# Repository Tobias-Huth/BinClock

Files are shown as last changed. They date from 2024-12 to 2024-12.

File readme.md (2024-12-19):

english version below!

# Mega Projekt: Binäre Anzeige der Uhzeit mit LEDS
Die Idee war schon länger vorhanden und nachdem es dieses spezielle Ding nicht zu kaufen gibt: Hab ich da was gemacht

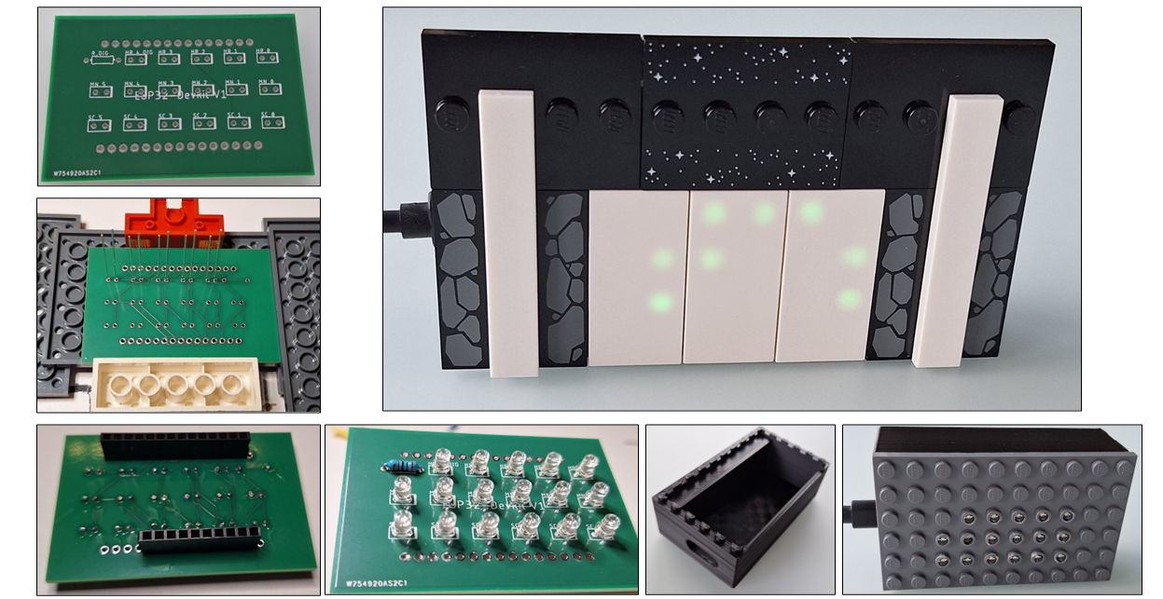
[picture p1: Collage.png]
image caption


## Allgemein:
Das ganze Projekt hat einen ESP32 (z.B [dieser](https://www.amazon.de/dp/B0DGG865GM)) als Kern. Der ESP hat 16 PWM-fähige Ausgänge. Das reicht fast, um die Uhrzeit anzuzeigen:
Minuten und Sekunden benötigen jeweils 6 Bit (0..63)
Die Stundenanzeige braucht 5 Bit (0..31). 
Das heißt, eine LED muss mit einem Widerstand fest beschalten werden, alle anderen können dimmbar sein. gar nicht so schlecht, machen wir so.
Nachdem diese Grundidee vorhanden ist, nun zur Umsetzung.

## Elektronik

Der zugegeben wirklich einfache Schaltplan für das Gerät ist in [Autodesk EAGLE](http://eagle.autodesk.com/eagle/software-versions/50) geschrieben. Die Software ist, soweit ich sehen kann, frei, nur eine Anmeldung ist nötig.
Um selbst was zu machen, empfehle ich dringend ein Tutorial wie dieses:
https://www.youtube.com/watch?v=1AXwjZoyNno
Damit versteht man die Bedienlogik und die Logik des Tools ganz gut.

Den Plan habe ich dann genutzt, um gerber-files (CNC-Dateien für die Platinen) herzustellen und bei [PCBway](https://www.pcbway.com/) zu bestellen. Die Anleitung [hier](https://www.pcbway.com/helpcenter/generate_gerber/Generate_Gerber_files_in_Eagle.html) hat bei mir sehr gut funktioniert.

## CAD / Gehäuse
Wie man unschwer erkennen kann, ist die Frontplatte eine Lego Bauplatte, 10x6 Noppen. Die Noppen ( ⌀ 4.9 mm) sind mit einem Bohrer 3,3mm ausgebohrt. So passen die 3mm-LEDs locker. Der erste Prototyp mit 3mm goßem Loch hat zwar schön geklemmt, die LEDs vertragen aber die Kräfte beim Aufsetzen nicht gut.
Die Platine benutzt das Lego-Rastermaß 8 mm. So passen die LEDs auf der Paltine sauber in die Löcher.
Das Gehäuse selbst ist in [FreeCAD](https://www.freecad.org/) konstruiert und dann gedruckt.

## Software
Die Software ist in [Arduino-IDE](https://www.arduino.cc/en/software) geschrieben. Die notwendigen Bibliotheken versuche ich weiter unten zusammenzutragen.
Der ESP stellt einen WLAN-Access-Point zu Verfügung. In diesem Netz serviert der ESP die Webseite, mit der die Uhr gestellt wird. Die Steuerung wird über http-request (POST) realisiert.
Die in [Brave](https://brave.com/) enthaltene KI hat mir wirklich gut geholfen, den Teil der Verarbeitung der http-requests im Backend einfach zu implementieren.
Ich hab die ASCII-Tabelle abprogrammiert, die Uhr kann mit ihrem 3x5 großen Anzeigefeld alle Buchstaben, Ziffern und ein paar Sonderzeichen darstellen.

---

## Stückliste
- 17 3-mm-LEDS wie diese :https://www.amazon.de/gp/product/B01BTYHOMC/
- PCB nach EAGLE-Plan
- ESP32 https://www.amazon.de/gp/product/B0DGG865GM/
- 2kOhm widerstand als Bremswiderstand für die LED am gigitalen Ausgang

---
---
# Mega Project: Binary Display of Time with LEDs
The idea had been around for a while, and since this special thing couldn’t be bought, I decided to make one myself.

image caption

## General:
The entire project is based on an ESP32 (e.g. [this one](https://www.amazon.de/dp/B0DGG865GM)), which has 16 PWM-capable outputs. This is almost enough to display the time:

Minutes and seconds each require 6 bits (0…63)
The hour display needs 5 bits (0…31). This means that one LED must be connected with a fixed resistor, and all others can be dimmable. Not so bad, let’s do it that way. Now that the basic idea is in place, let’s move on to the implementation.

## Electronics
The admittedly very simple circuit diagram for the device is written in [Autodesk EAGLE](http://eagle.autodesk.com/eagle/software-versions/50). The software is, as far as I can see, free, but requires registration. To get started, I strongly recommend a tutorial like this: https://www.youtube.com/watch?v=1AXwjZoyNno 
This will help you understand the logic and tool usage quite well.

I used the plan to create gerber files (CNC files for the boards) and ordered them from [PCBway](https://www.pcbway.com/). The instructions [hier](https://www.pcbway.com/helpcenter/generate_gerber/Generate_Gerber_files_in_Eagle.html) worked very well for me.

## CAD / Housing
As you can easily recognize, the front panel is a Lego building plate, 10x6 studs. The studs (⌀ 4.9 mm) are drilled with a 3.3mm drill bit. This allows the 3mm LEDs to fit snugly. The first prototype with a 3mm large hole did fit nicely, but the LEDs don’t handle the forces of being placed well. The board uses the Lego grid size of 8 mm. This allows the LEDs on the board to fit cleanly into the holes. The housing itself is constructed in [FreeCAD](https://www.freecad.org/) and then printed at home.

## Software
The software is written in the [Arduino-IDE](https://www.arduino.cc/en/software). I’ll try to gather the necessary libraries below. The ESP provides a Wi-Fi access point. In this network, the ESP serves the webpage that sets the clock. The control is realized via HTTP requests (POST). Especially the http-request part on the backend was strongly supported by AI, namely the one included in [Brave](https://brave.com/).
I programmed the ASCII table, and the clock can display all letters, numbers, and a few special characters with its 3x5 large display field.

---
## Parts List
- 17 3mm LEDs like these: https://www.amazon.de/gp/product/B01BTYHOMC/
- PCB according to EAGLE plan
- ESP32: https://www.amazon.de/gp/product/B0DGG865GM/
- 2kOhm resistor as a braking resistor for the LED at the digital output

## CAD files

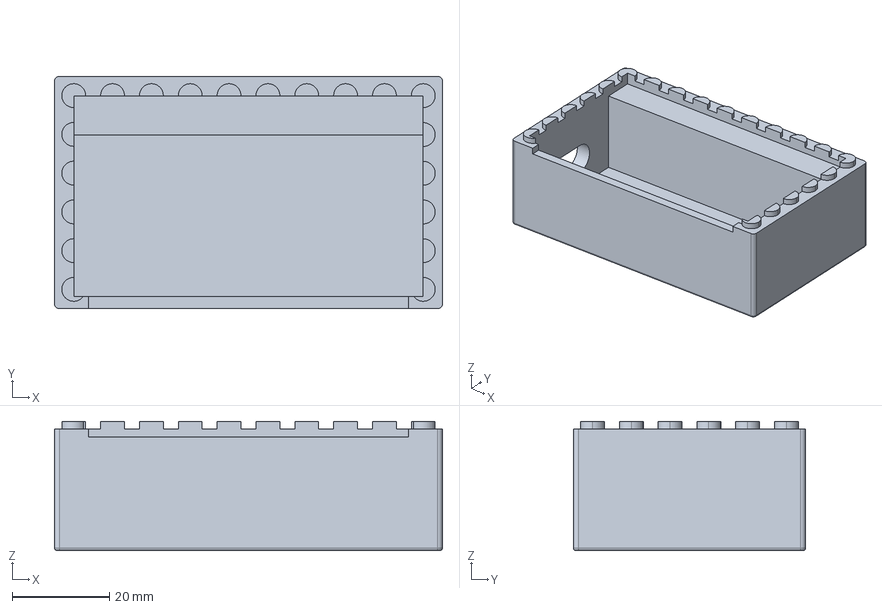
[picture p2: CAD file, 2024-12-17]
CAD/BinClock_House.FCStd
79.7 x 47.7 x 26.5 mm

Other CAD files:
CAD/BinClock_Assembly.FCStd
CAD/BinClock_House.stl

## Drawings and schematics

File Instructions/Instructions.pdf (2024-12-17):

## Temple Of Time

1

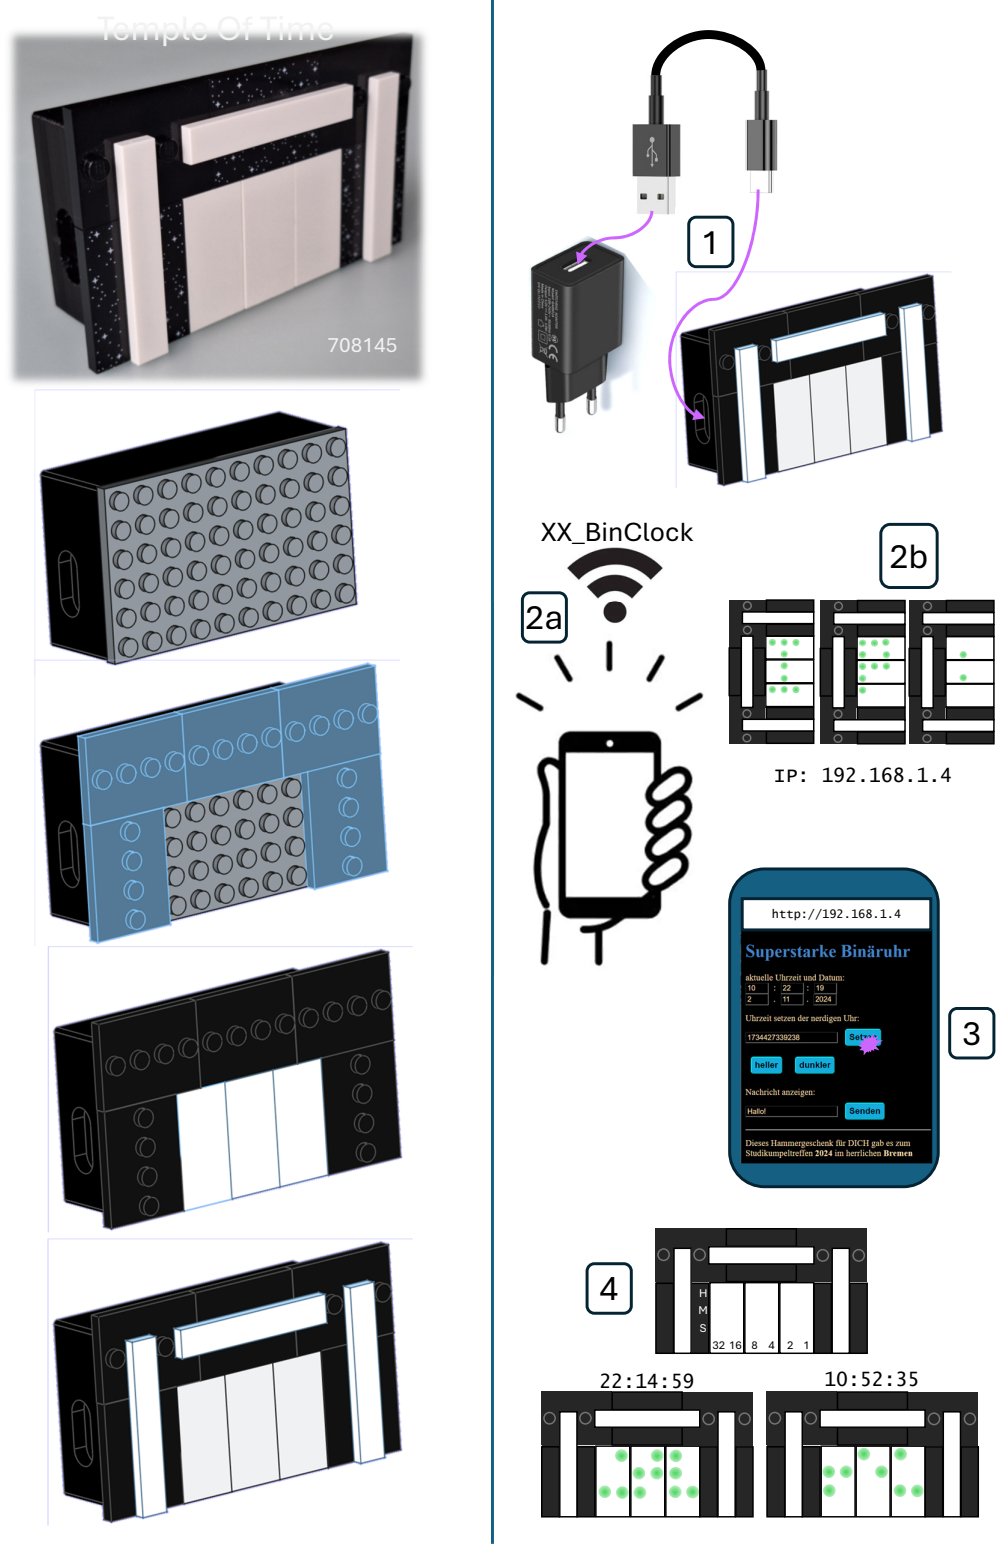
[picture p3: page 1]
XX_BinClock; http://192.168.1.4

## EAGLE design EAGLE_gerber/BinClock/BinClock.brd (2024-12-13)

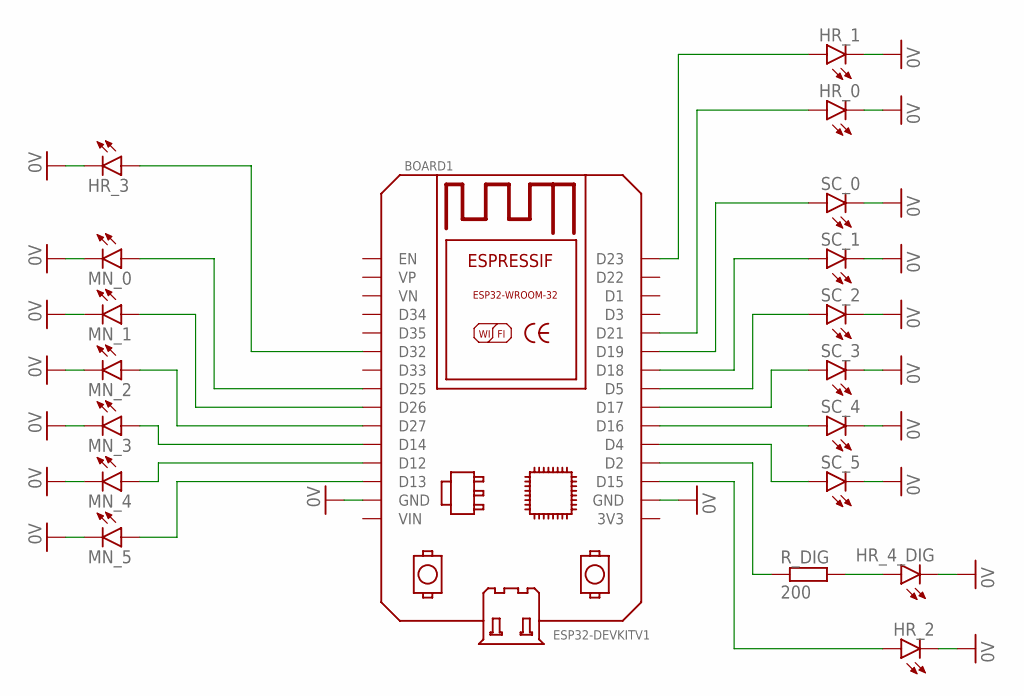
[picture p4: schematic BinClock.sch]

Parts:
BOARD1: ESP32DEVKITV1; ESP32-DEVKITV1
HR_0, HR_1, HR_2, HR_3, HR_4_DIG: LEDSQR2X5; LED2X5
MN_0, MN_1, MN_2, MN_3, MN_4, MN_5: LEDSQR2X5; LED2X5
R_DIG: 200; 0204/7
SC_0, SC_1, SC_2, SC_3, SC_4, SC_5: LEDSQR2X5; LED2X5

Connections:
0V: BOARD1.GND, BOARD1.GND@1 (GND), HR_0.K (C), HR_1.K (C), HR_2.K (C), HR_3.K (C), HR_4_DIG.K (C), MN_0.K (C), MN_1.K (C), MN_2.K (C), MN_3.K (C), MN_4.K (C), MN_5.K (C), SC_0.K (C), SC_1.K (C), SC_2.K (C), SC_3.K (C), SC_4.K (C), SC_5.K (C)
unnamed: BOARD1.D4, SC_5.A
unnamed: BOARD1.D16, SC_4.A
unnamed: BOARD1.D17, SC_3.A
unnamed: BOARD1.D5, SC_2.A
unnamed: BOARD1.D18, SC_1.A
unnamed: BOARD1.D19, SC_0.A
unnamed: BOARD1.D2, R_DIG.1
unnamed: BOARD1.D13, MN_5.A
unnamed: BOARD1.D12, MN_4.A
unnamed: BOARD1.D14, MN_3.A
unnamed: BOARD1.D27, MN_2.A
unnamed: BOARD1.D26, MN_1.A
unnamed: BOARD1.D25, MN_0.A
unnamed: HR_4_DIG.A, R_DIG.2
unnamed: BOARD1.D21, HR_0.A
unnamed: BOARD1.D23, HR_1.A
unnamed: BOARD1.D15, HR_2.A
unnamed: BOARD1.D32, HR_3.A

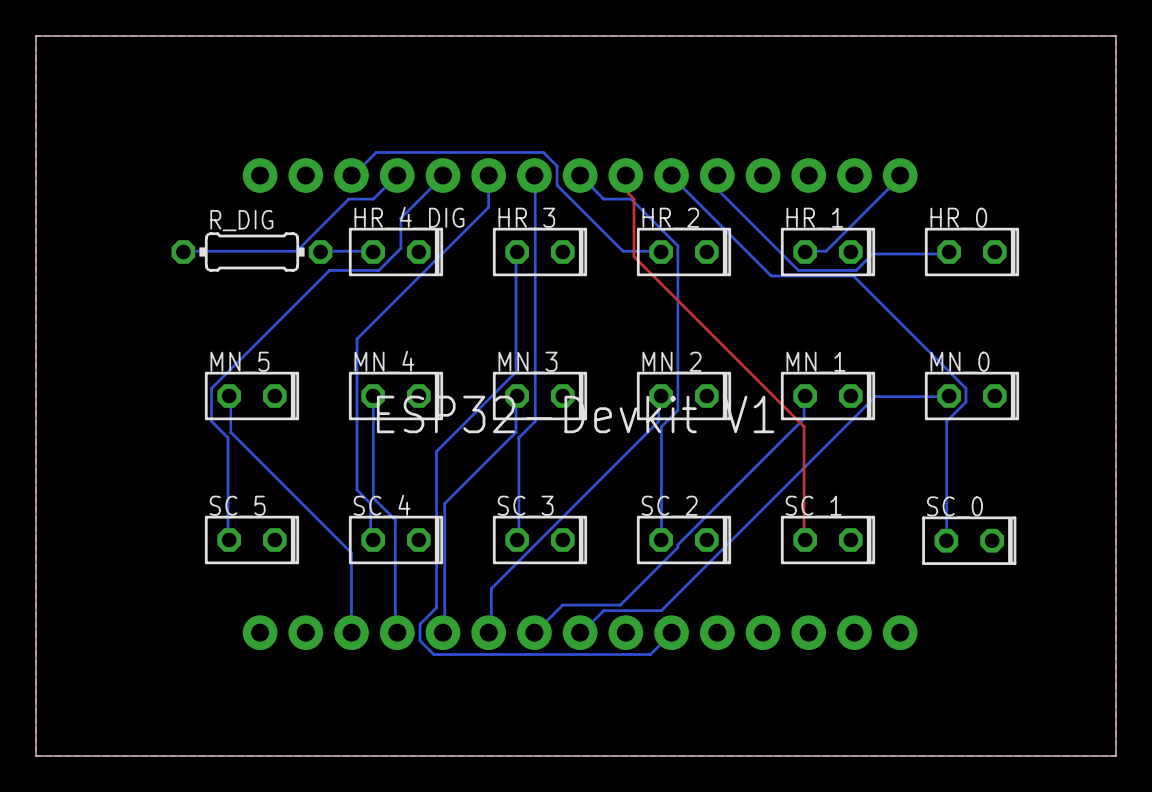
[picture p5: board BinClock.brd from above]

Board: 2 copper layers, 60.0 x 40.0 mm, 19 parts (1 on the bottom side), 19 nets.

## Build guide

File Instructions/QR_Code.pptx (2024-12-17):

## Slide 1

https://github.com/Tobias-Huth/BinClock

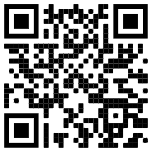
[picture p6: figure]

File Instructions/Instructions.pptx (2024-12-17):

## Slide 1

Temple Of Time

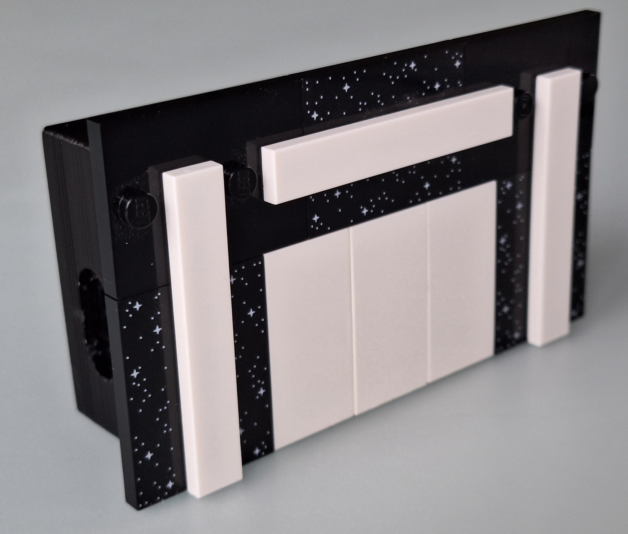
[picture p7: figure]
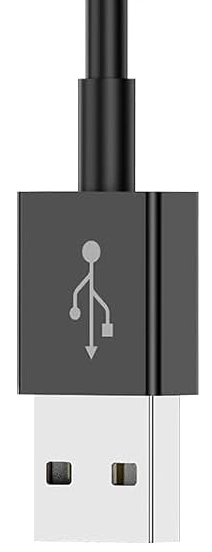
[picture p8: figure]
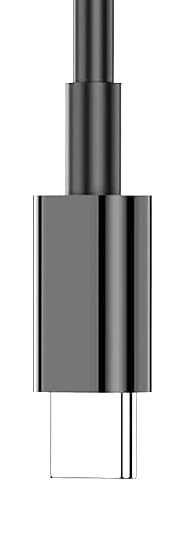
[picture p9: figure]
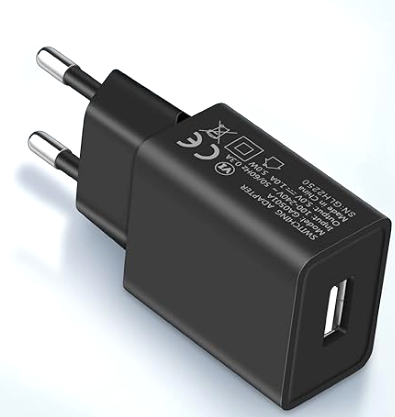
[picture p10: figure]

1

708145

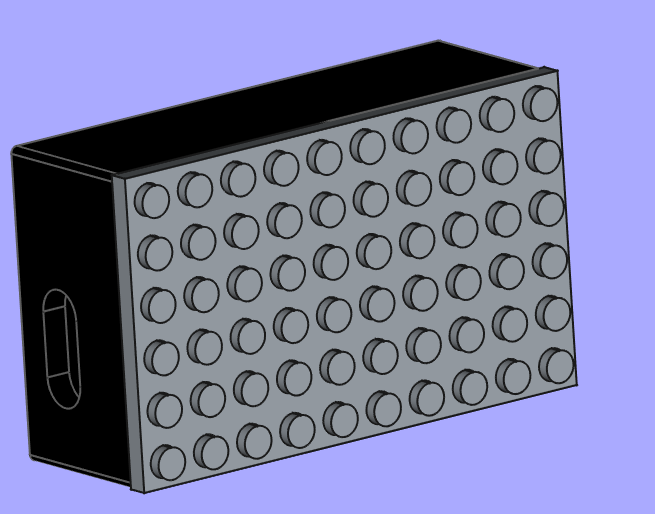
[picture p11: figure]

XX_BinClock

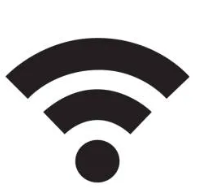
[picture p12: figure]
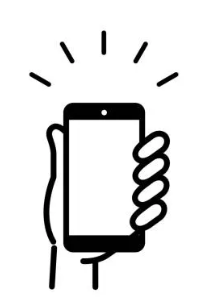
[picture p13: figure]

2a

2b

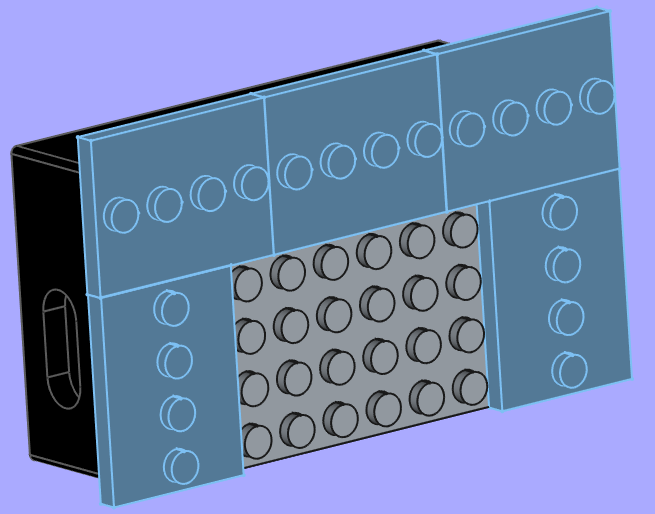
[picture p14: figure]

IP: 192.168.1.4

http://192.168.1.4

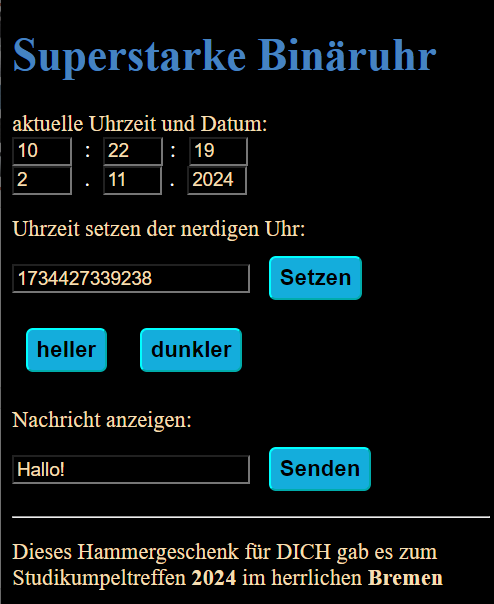
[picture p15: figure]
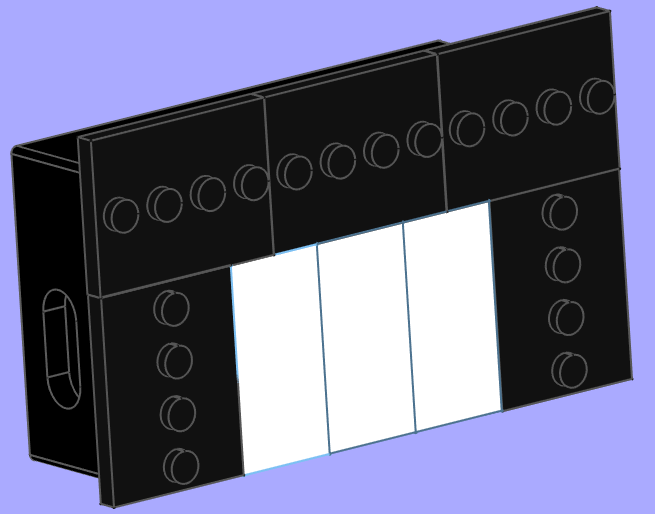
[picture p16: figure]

3

M

H

22:14:59

S

32

16

8

4

2

1

10:52:35

4

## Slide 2

1

1

XX_BinClock

XX_BinClock

2a

2b

2a

2b

IP: 192.168.1.4

http://192.168.1.4

IP: 192.168.1.4

http://192.168.1.4

3

3

M

H

22:14:59

S

32

16

8

4

2

1

10:52:35

4

M

H

22:14:59

S

32

16

8

4

2

1

10:52:35

4

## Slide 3

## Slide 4

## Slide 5

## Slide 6

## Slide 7

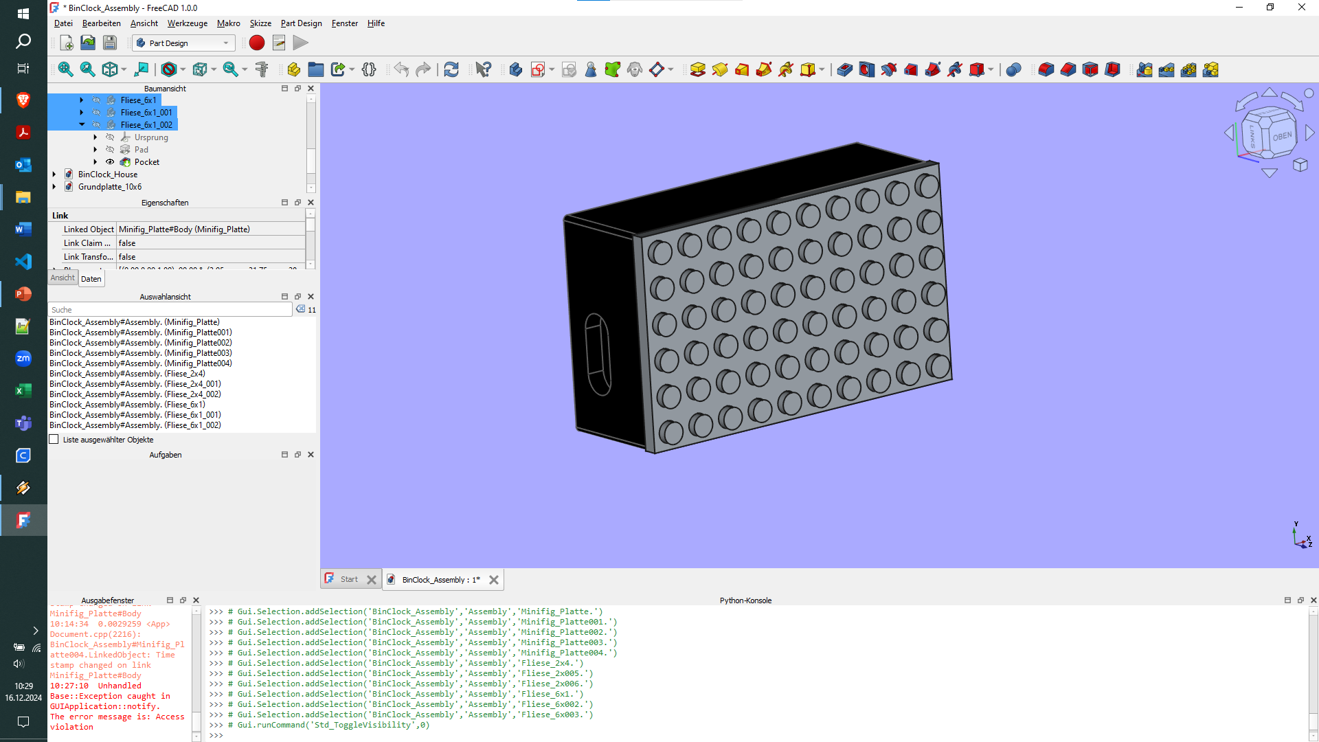
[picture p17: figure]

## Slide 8

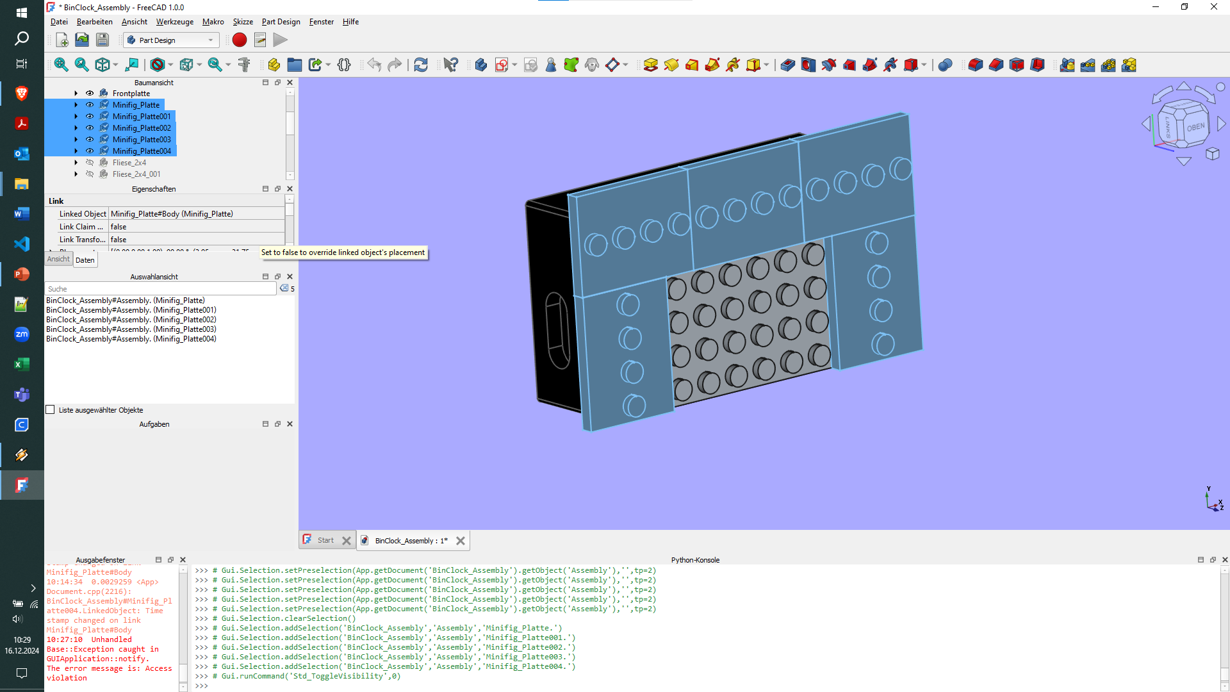
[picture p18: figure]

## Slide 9

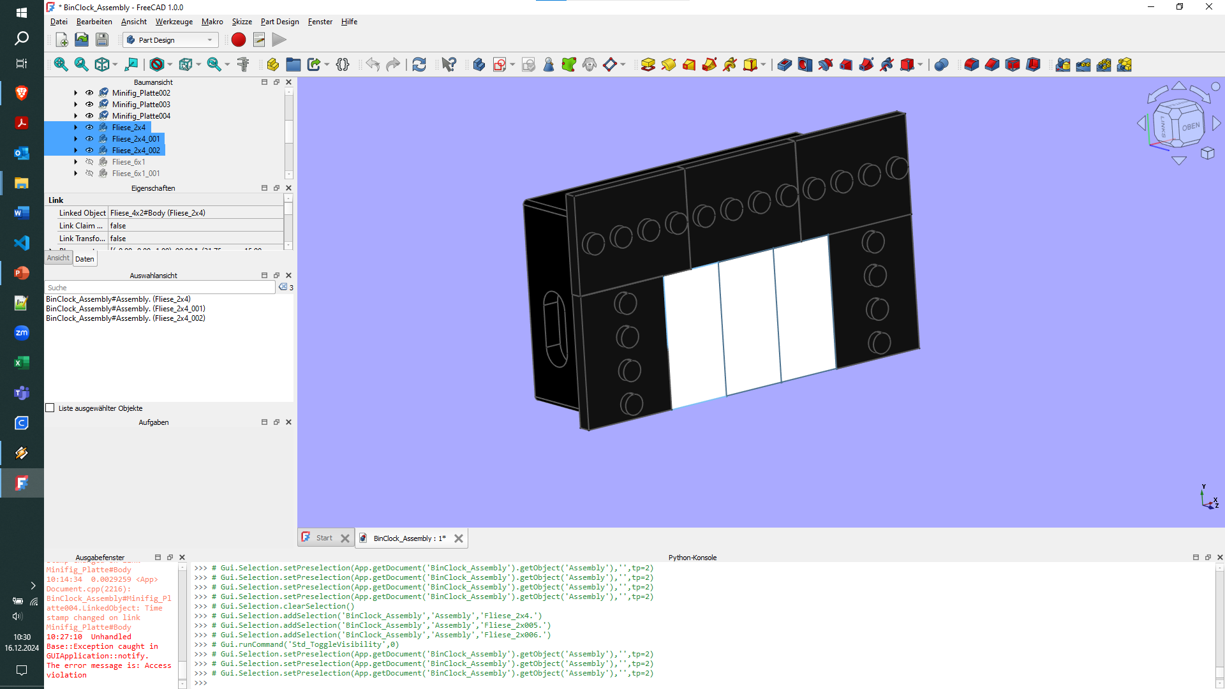
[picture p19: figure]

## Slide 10

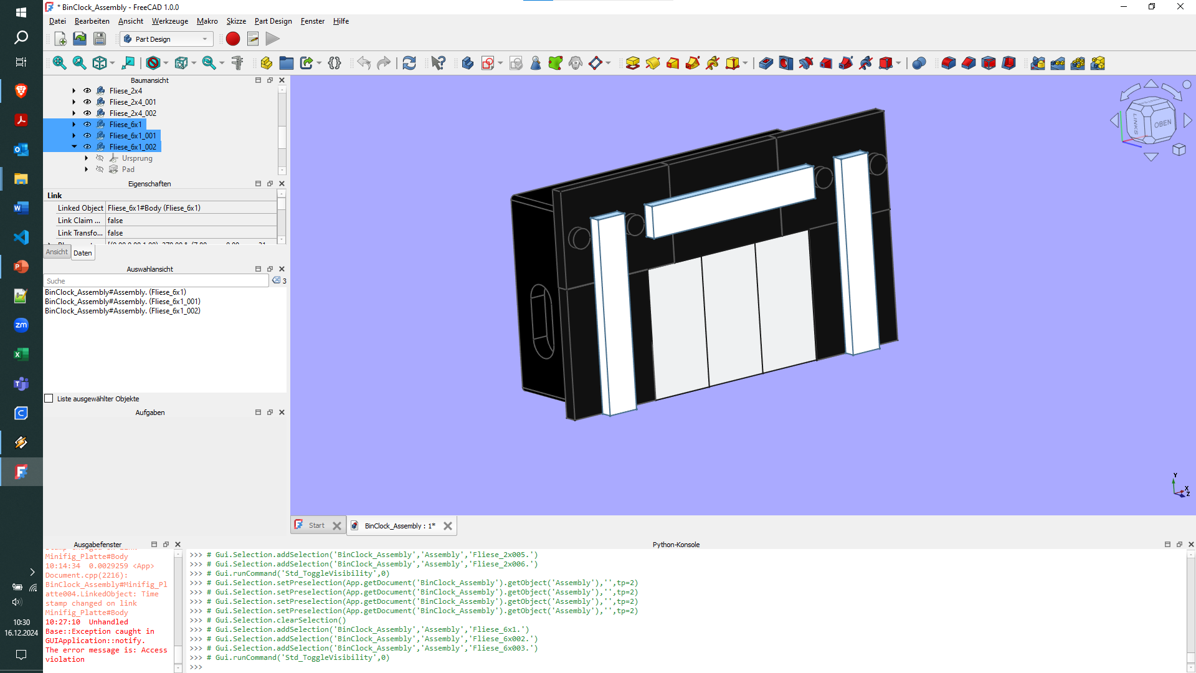
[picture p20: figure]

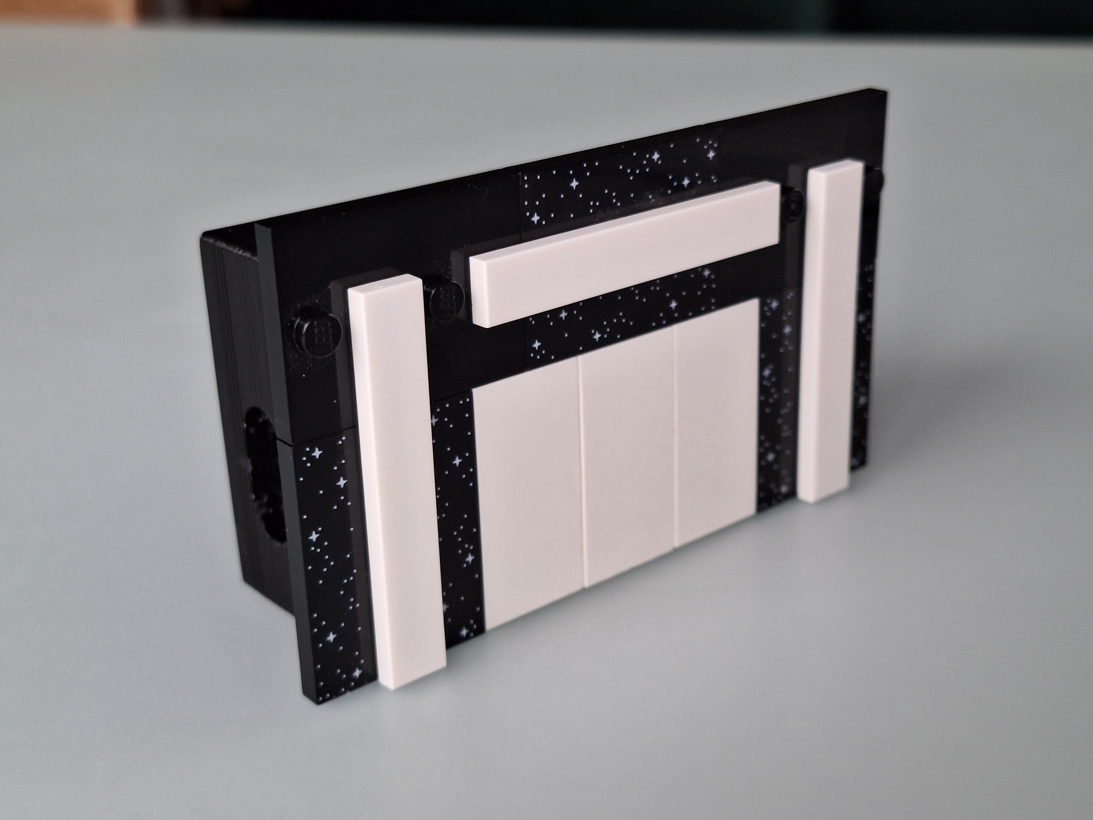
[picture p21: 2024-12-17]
Instructions/20241216_095956.jpg

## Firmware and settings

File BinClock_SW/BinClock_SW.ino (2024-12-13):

#include <WiFi.h>
#include <WebServer.h>
#include <ESP32Time.h>

#include "website.h"
#include "Pins_and_Counters.h"
#include "ASCII_Table.h"

const char* ssid = "BinClock";
const char* password = "";

int sec_cnt = -3;

int Sec_Val = 0;
int Min_Val = 0;
int Hur_Val = 0;

int bright_inc = 2;

int sec_bright = 10;
int min_bright = 10;
int hur_bright = 10;
int max_bright = 40;

bool IP_disp_done = false;

bool disp_user_Flag = false;
int disp_user_cnt = 0;
String message_string = "";
char* test_Arr = new char[128];


ESP32Time rtc(3600);  // set timezone to german gmt+1

IPAddress myIP;

WebServer server(80);

void setup() {
  pinMode(sec_Pin0, OUTPUT);
  pinMode(sec_Pin1, OUTPUT);
  pinMode(sec_Pin2, OUTPUT);
  pinMode(sec_Pin3, OUTPUT);
  pinMode(sec_Pin4, OUTPUT);
  pinMode(sec_Pin5, OUTPUT);

  pinMode(min_Pin0, OUTPUT);
  pinMode(min_Pin1, OUTPUT);
  pinMode(min_Pin2, OUTPUT);
  pinMode(min_Pin3, OUTPUT);
  pinMode(min_Pin4, OUTPUT);
  pinMode(min_Pin5, OUTPUT);

  pinMode(hur_Pin0, OUTPUT);
  pinMode(hur_Pin1, OUTPUT);
  pinMode(hur_Pin2, OUTPUT);
  pinMode(hur_Pin3, OUTPUT);
  pinMode(hur_Pin4, OUTPUT);

  Serial.begin(115200);
  WiFi.softAP(ssid, password);
  myIP = WiFi.softAPIP();

  server.on("/", handleRoot);
  server.begin();
}

void handleRoot() {

  if (server.method() == HTTP_POST) {
    String str_time_set = server.arg("set_T");
    String str_set_dimmer = server.arg("dimmer");
    String str_set_brighter = server.arg("brighter");
    String str_message = server.arg("message_Box");

    if (str_time_set.length() > 0) {
      Serial.println("Received post to set new time: " + str_time_set);
      char* pEnd;
      long long int time_val = strtoull(str_time_set.c_str(), &pEnd, 10) / 1000;
      rtc.setTime(time_val);
    }
    if (str_set_brighter.length() > 0) {
      Serial.println("set brightness higher");
      sec_bright += bright_inc;
      min_bright += bright_inc;
      hur_bright += bright_inc;
      if (sec_bright > max_bright) { sec_bright = max_bright; };
      if (min_bright > max_bright) { min_bright = max_bright; };
      if (hur_bright > max_bright) { hur_bright = max_bright; };
    }
    if (str_set_dimmer.length() > 0) {
      Serial.println("set the brightness lower");
      sec_bright -= bright_inc;
      min_bright -= bright_inc;
      hur_bright -= bright_inc;
      if (sec_bright < 1) { sec_bright = 1; };
      if (min_bright < 1) { min_bright = 1; };
      if (hur_bright < 1) { hur_bright = 1; };

      Serial.println(sec_bright);
    }
    if (str_message.length() > 0) {
      message_string = str_message;
      disp_user_Flag = true;
      disp_user_cnt = 0;
      strcpy(test_Arr, message_string.c_str());
    }

    server.send(200, "text/html", websiteHTML);

  } else {
    server.send(200, "text/html", websiteHTML);
  }
}

void loop() {

  server.handleClient();
  if (!IP_disp_done) {
    if (sec_cnt <= 0) {
      Sec_Val = 63;
      Min_Val = 63;
      Hur_Val = 31;
    }

    sec_cnt++;

    if (sec_cnt == 1) {
      Sec_Val = ASCII_table['I'-32][2];
      Min_Val = ASCII_table['I'-32][1];
      Hur_Val = ASCII_table['I'-32][0];
    }

    if (sec_cnt == 2) {
      Sec_Val = ASCII_table['P'-32][2];
      Min_Val = ASCII_table['P'-32][1];
      Hur_Val = ASCII_table['P'-32][0];
    }

    if (sec_cnt == 3) {
      Sec_Val = ASCII_table[':'-32][2];
      Min_Val = ASCII_table[':'-32][1];
      Hur_Val = ASCII_table[':'-32][0];
    }

    if ((sec_cnt > 3) & (sec_cnt < 16)) {
      char* temp_Arr = new char[35];
      strcpy(temp_Arr, myIP.toString(0).c_str());
        Sec_Val = ASCII_table[(temp_Arr[sec_cnt - 4]) - 32][2];
        Min_Val = ASCII_table[(temp_Arr[sec_cnt - 4]) - 32][1];
        Hur_Val = ASCII_table[(temp_Arr[sec_cnt - 4]) - 32][0];
    }
    if (sec_cnt == 16) {
      Sec_Val = 63;
      Min_Val = 63;
      Hur_Val = 31;
      IP_disp_done = true;
      sec_cnt = 0;
    }
  } else if (disp_user_Flag) {
    Sec_Val = ASCII_table[(int)test_Arr[disp_user_cnt] - 32][2];
    Min_Val = ASCII_table[(int)test_Arr[disp_user_cnt] - 32][1];
    Hur_Val = ASCII_table[(int)test_Arr[disp_user_cnt] - 32][0];
    disp_user_cnt++;
  } else {
    Sec_Val = rtc.getSecond();
    Min_Val = rtc.getMinute();
    Hur_Val = rtc.getHour(true);
  }

  sec_Val0 = (Sec_Val >> 0) & (0x1);
  sec_Val1 = (Sec_Val >> 1) & (0x1);
  sec_Val2 = (Sec_Val >> 2) & (0x1);
  sec_Val3 = (Sec_Val >> 3) & (0x1);
  sec_Val4 = (Sec_Val >> 4) & (0x1);
  sec_Val5 = (Sec_Val >> 5) & (0x1);

  min_Val0 = (Min_Val >> 0) & (0x1);
  min_Val1 = (Min_Val >> 1) & (0x1);
  min_Val2 = (Min_Val >> 2) & (0x1);
  min_Val3 = (Min_Val >> 3) & (0x1);
  min_Val4 = (Min_Val >> 4) & (0x1);
  min_Val5 = (Min_Val >> 5) & (0x1);

  hur_Val0 = (Hur_Val >> 0) & (0x1);
  hur_Val1 = (Hur_Val >> 1) & (0x1);
  hur_Val2 = (Hur_Val >> 2) & (0x1);
  hur_Val3 = (Hur_Val >> 3) & (0x1);
  hur_Val4 = (Hur_Val >> 4) & (0x1);

  if (!IP_disp_done | disp_user_Flag) {
    analogWrite(sec_Pin0, 0);  // 15
    analogWrite(sec_Pin1, 0);
    analogWrite(sec_Pin2, 0);
    analogWrite(sec_Pin3, 0);
    analogWrite(sec_Pin4, 0);
    analogWrite(sec_Pin5, 0);
    analogWrite(min_Pin0, 0);  // 25
    analogWrite(min_Pin1, 0);
    analogWrite(min_Pin2, 0);
    analogWrite(min_Pin3, 0);
    analogWrite(min_Pin4, 0);
    analogWrite(min_Pin5, 0);
    analogWrite(hur_Pin0, 0);  // 10
    analogWrite(hur_Pin1, 0);
    analogWrite(hur_Pin2, 0);
    analogWrite(hur_Pin3, 0);
    digitalWrite(hur_Pin4, 0);
    delay(300);
  }
  // this needs to be placed here because otherwise, the last element of the message is displayed for a too short period of time.
  if (disp_user_cnt > message_string.length() - 1) {
    disp_user_Flag = false;
    message_string = "";
  }
  analogWrite(sec_Pin0, sec_Val0 * sec_bright);  // 15
  analogWrite(sec_Pin1, sec_Val1 * sec_bright);
  analogWrite(sec_Pin2, sec_Val2 * sec_bright);
  analogWrite(sec_Pin3, sec_Val3 * sec_bright);
  analogWrite(sec_Pin4, sec_Val4 * sec_bright);
  analogWrite(sec_Pin5, sec_Val5 * sec_bright);
  analogWrite(min_Pin0, min_Val0 * min_bright);  // 25
  analogWrite(min_Pin1, min_Val1 * min_bright);
  analogWrite(min_Pin2, min_Val2 * min_bright);
  analogWrite(min_Pin3, min_Val3 * min_bright);
  analogWrite(min_Pin4, min_Val4 * min_bright);
  analogWrite(min_Pin5, min_Val5 * min_bright);
  analogWrite(hur_Pin0, hur_Val0 * hur_bright);  // 10
  analogWrite(hur_Pin1, hur_Val1 * hur_bright);
  analogWrite(hur_Pin2, hur_Val2 * hur_bright);
  analogWrite(hur_Pin3, hur_Val3 * hur_bright);
  digitalWrite(hur_Pin4, hur_Val4);

  if (!IP_disp_done) {
    delay(1000);
  } else {
    delay(500);
  }
}

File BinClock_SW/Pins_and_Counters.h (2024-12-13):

// definitions for the output pin numbers
// and the bits to send to the individual LEDS

int sec_Pin0 = 19;
int sec_Pin1 = 18;
int sec_Pin2 = 05;
int sec_Pin3 = 17;
int sec_Pin4 = 16;
int sec_Pin5 = 04;

int min_Pin0 = 25;
int min_Pin1 = 26;
int min_Pin2 = 27;
int min_Pin3 = 14;
int min_Pin4 = 12;
int min_Pin5 = 13;

int hur_Pin0 = 21;  // OK
int hur_Pin1 = 23;  // OK
int hur_Pin2 = 15;
int hur_Pin3 = 32;  //OK
int hur_Pin4 = 02;  // DIGITAL PIN!

int sec_Val0 = 00;
int sec_Val1 = 00;
int sec_Val2 = 00;
int sec_Val3 = 00;
int sec_Val4 = 00;
int sec_Val5 = 00;

int min_Val0 = 00;
int min_Val1 = 00;
int min_Val2 = 00;
int min_Val3 = 00;
int min_Val4 = 00;
int min_Val5 = 00;

int hur_Val0 = 00;
int hur_Val1 = 00;
int hur_Val2 = 00;
int hur_Val3 = 00;
int hur_Val4 = 00;

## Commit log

2024-12-13 initial commit with all stuff: CAD-Data for housing EAGLE and gerber files for PCB Arduino-Project for ESP32
    [BinClock.brd, BinClock.sch, BinClock_House.FCStd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]
2024-12-17 made quick mock ups of the lego plates for making viusals for the instructions imroved the readmes added raw data for instructions (ppt) added intructions pdf made assembly in freecad for the instruc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
    [BinClock_Assembly.FCStd, BinClock_House.FCStd]
2024-12-19 added nice overview picture, powerpoint ftw!
